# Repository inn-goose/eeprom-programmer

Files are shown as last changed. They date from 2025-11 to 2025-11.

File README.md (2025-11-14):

# EEPROM Programmer

> [!IMPORTANT]
> This project concerns **external** EEPROM chips, not the built-in Arduino EEPROM memory.

## TLDR

🚧 WIP 🚧

## Wiring Diagram

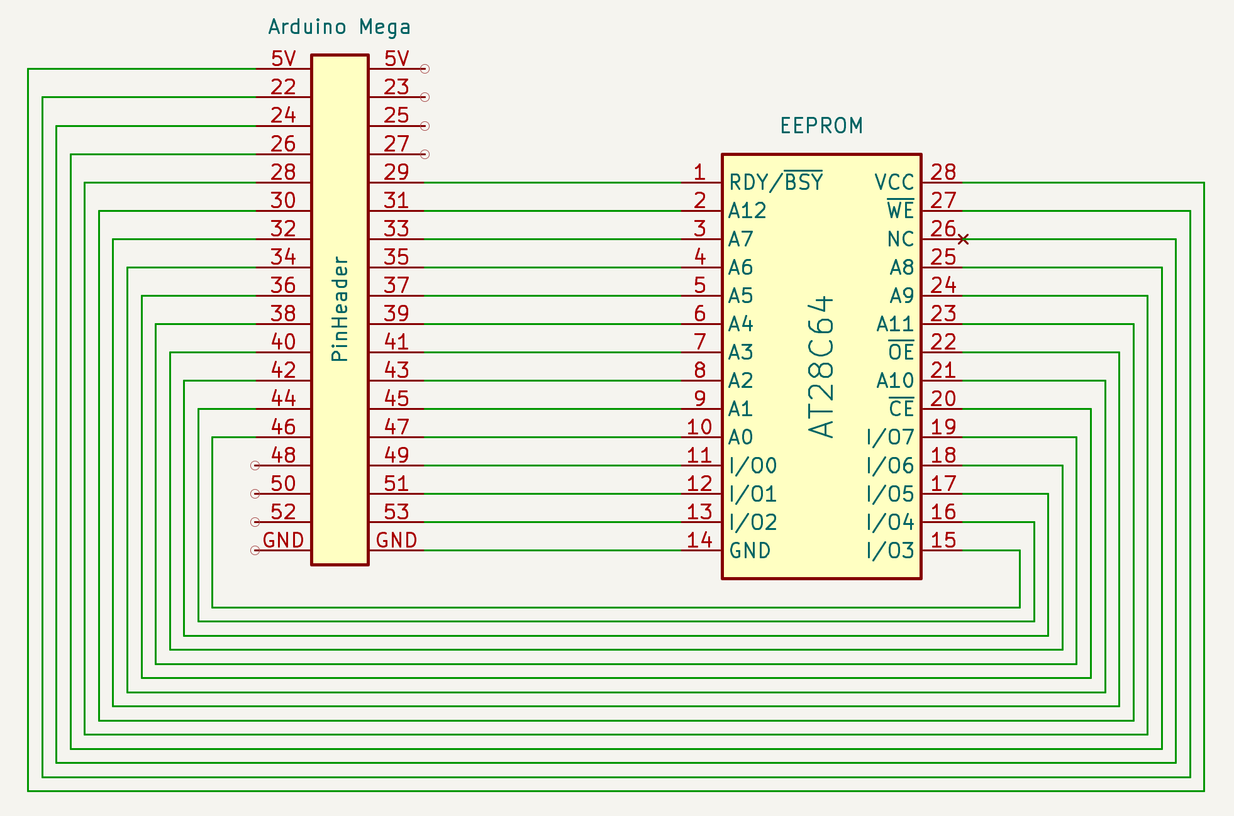
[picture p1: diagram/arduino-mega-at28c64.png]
Wiring Diagram: Arduino Mega and AT28C64


## EEPROM Programmer on Arduino

set pins layout in `eeprom_wiring.h`

Programmer interface:
```cpp
// initialize chip pinout 
ErrorCode init_chip(const String& chip_type);

// set read mode
ErrorCode set_read_mode(const int page_size_bytes);

// read one page
ErrorCode read_page(const int page_no, uint8_t* bytes);

// set write mode
ErrorCode set_write_mode(const int page_size_bytes);

// write one page
ErrorCode write_page(const int page_no, const uint8_t* bytes);
```

### JSON-RPC API

Arduino IDE's *Serial Monitor* on `115200` baud

`init_chip(chip_type: str)`

```json
{"jsonrpc":"2.0", "id":0, "method": "init_chip", "params": ["AT28C64"]}
```

`set_read_mode(page_size_bytes: int)`

```json
{"jsonrpc":"2.0", "id":0, "method": "set_read_mode", "params": [4]}
```

`read_page(page_no: int)`

```json
{"jsonrpc":"2.0", "id":0, "method": "read_page", "params": [0]}
```

`set_write_mode(page_size_bytes: int)`

```json
{"jsonrpc":"2.0", "id":0, "method": "set_write_mode", "params": [4]}
```

`write_page(page_no: int, data: array[int])`

```json
{"jsonrpc":"2.0", "id":0, "method": "write_page","params": [0, [127, 127, 127, 127]]}
```

#### Write Operation Sequence

```json
{"jsonrpc":"2.0", "id":0, "method": "init_chip", "params": ["AT28C64"]}
{"jsonrpc":"2.0", "id":0, "method": "set_write_mode", "params": [4]}
{"jsonrpc":"2.0", "id":0, "method": "write_page","params": [0, [120, 130, 140, 150]]}
{"jsonrpc":"2.0", "id":0, "method": "write_page","params": [50, [20, 30, 40, 50]]}
{"jsonrpc":"2.0", "id":0, "method": "get_write_perf","params": []}
```

#### Read Operation Sequence

```json
{"jsonrpc":"2.0", "id":0, "method": "init_chip", "params": ["AT28C64"]}
{"jsonrpc":"2.0", "id":0, "method": "set_read_mode", "params": [4]}
{"jsonrpc":"2.0", "id":0, "method": "read_page", "params": [0]}
{"jsonrpc":"2.0", "id":0, "method": "read_page", "params": [50]}
```

## EEPROM Programmer python CLI

> [!CAUTION]
> During read operations with the EEPROM Programmer, the chip's `!WE` pin **MUST** be connected to `VCC` using a jumper wire to disable the write mode. Otherwise, invoking the CLI may corrupt data on the chip due to Arduino's internal behavior. [Details](https://goose.sh/blog/eeprom-programmer-5-data-corruption/)

Uses the [Serial JSON RPC](https://github.com/inn-goose/serial-json-rpc-arduino) interface.

### init CLI

```bash
pip3 install virtualenv

PATH=${PATH}:~/Library/Python/3.9/bin/ ./env/init.sh

source venv/bin/activate

deactivate
```

### Usage

```bash
source venv/bin/activate

python3 -m serial.tools.list_ports
...
/dev/cu.usbmodem2101
```

#### prepare data

```bash
mkdir ./tmp

# get a "real" EEPROM dump
curl -LJ --output tmp/zenith_zt1_eeprom.bin "https://github.com/misterblack1/zenith_zt1/raw/refs/heads/main/444-187%20U114%20ROM%202732.bin"
```

#### read

```bash
source venv/bin/activate
export PYTHONPATH=./eeprom_programmer_cli/:$PYTHONPATH

# read data to file
./eeprom_programmer_cli/cli.py /dev/cu.usbmodem2101 -p AT28C64 --read tmp/dump_eeprom.bin

# convert to HEX
xxd tmp/dump_eeprom.bin > tmp/dump_eeprom.hex
```

#### erase

```bash
source venv/bin/activate
export PYTHONPATH=./eeprom_programmer_cli/:$PYTHONPATH

# erase with FF pattern
./eeprom_programmer_cli/cli.py /dev/cu.usbmodem2101 -p AT28C64 --erase --erase-pattern FF
```

#### write

```bash
source venv/bin/activate
export PYTHONPATH=./eeprom_programmer_cli/:$PYTHONPATH

# write data from file
./eeprom_programmer_cli/cli.py /dev/cu.usbmodem2101 -p AT28C64 --write test_bin/4_echo_orbit.bin

# skip erase
./eeprom_programmer_cli/cli.py /dev/cu.usbmodem2101 -p AT28C64 --write test_bin/4_echo_orbit.bin --skip-erase

# custom erase pattern
./eeprom_programmer_cli/cli.py /dev/cu.usbmodem2101 -p AT28C64 --write test_bin/4_echo_orbit.bin --erase-pattern CC
```

#### verify

```bash
source venv/bin/activate
export PYTHONPATH=./eeprom_programmer_cli/:$PYTHONPATH

# read data and verify it against the file
./eeprom_programmer_cli/cli.py /dev/cu.usbmodem2101 -p AT28C64 --verify test_bin/4_echo_orbit_AT28C64_ff.bin
```

## XGecu Programmer as a Reference

Use the [`minipro`](https://formulae.brew.sh/formula/minipro) utility to perform read and write operations with the XGecu programmer

```bash
brew install minipro

# write the "real" dump to the chip
minipro --device AT28C64 -s -u --write test_bin/4_echo_orbit.bin
minipro --device AT28C64 -s -u --write test_bin/64_the_red_migration.bin
minipro --device AT28C256 -s -u --write test_bin/256_the_geometry_of_flight.bin

# read the data
minipro --device AT28C64 -u --read tmp/dump_xgecu.bin
minipro --device AT28C256 -u --read tmp/dump_xgecu.bin

# convert to HEX
xxd tmp/dump_xgecu.bin > tmp/dump_xgecu.hex

# compare
vimdiff tmp/dump_eeprom.hex tmp/dump_xgecu.hex
```

## Tests

### prepare

```bash
source venv/bin/activate
export PYTHONPATH=./eeprom_programmer_cli/:$PYTHONPATH
```

### erase

```bash
# >> remove jumper wire
./eeprom_programmer_cli/cli.py /dev/cu.usbmodem2101 -p AT28C64 --erase --erase-pattern BB --collect-write-performance

# >> set jumper wire
./eeprom_programmer_cli/cli.py /dev/cu.usbmodem2101 -p AT28C64 --read tmp/dump_eeprom.bin

xxd tmp/dump_eeprom.bin | less
```

### write and read

```bash
# >> remove jumper wire
./eeprom_programmer_cli/cli.py /dev/cu.usbmodem2101 -p AT28C64 --write test_bin/4_echo_orbit.bin --erase-pattern BB --collect-write-performance

# >> set jumper wire
./eeprom_programmer_cli/cli.py /dev/cu.usbmodem2101 -p AT28C64 --read tmp/dump_eeprom.bin

xxd tmp/dump_eeprom.bin > tmp/dump_eeprom.hex
vimdiff tmp/dump_eeprom.hex tmp/4_echo_orbit.hex
```

### verify

```bash
# >> remove jumper wire
./eeprom_programmer_cli/cli.py /dev/cu.usbmodem2101 -p AT28C64 --write test_bin/4_echo_orbit.bin --collect-write-performance

# >> set jumper wire
./eeprom_programmer_cli/cli.py /dev/cu.usbmodem2101 -p AT28C64 --verify test_bin/4_echo_orbit_AT28C64_ff.bin
```

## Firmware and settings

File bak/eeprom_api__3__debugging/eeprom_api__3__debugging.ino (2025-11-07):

#include "eeprom_wiring.h"
#include "eeprom_28c64_api.h"

using namespace EepromApiLibrary;


// helper functions

enum LedColor { NO_LED_,
                LED_RED_,
                LED_GREEN_,
                LED_BLUE_ };

void setBuiltinLed(LedColor led_color) {
#ifdef LEDR
  // reverse logic. HIGH == off, LOW == on
  switch (led_color) {
    case LedColor::LED_RED_:
      digitalWrite(LEDR, LOW);
      digitalWrite(LEDG, HIGH);
      digitalWrite(LEDB, HIGH);
      break;
    case LedColor::LED_GREEN_:
      digitalWrite(LEDR, HIGH);
      digitalWrite(LEDG, LOW);
      digitalWrite(LEDB, HIGH);
      break;
    case LedColor::LED_BLUE_:
      digitalWrite(LEDR, HIGH);
      digitalWrite(LEDG, HIGH);
      digitalWrite(LEDB, LOW);
      break;
    case LedColor::NO_LED_:
    default:
      digitalWrite(LEDR, HIGH);
      digitalWrite(LEDG, HIGH);
      digitalWrite(LEDB, HIGH);
      break;
  }
#else
  switch (led_color) {
    case LedColor::LED_RED_:
    case LedColor::LED_GREEN_:
    case LedColor::LED_BLUE_:
      digitalWrite(LED_BUILTIN, HIGH);
      break;
    default:
      digitalWrite(LED_BUILTIN, LOW);
      break;
  }
#endif
}


// EEPROM 28C64

Eeprom28C64Api eeprom28C64Api(
  // address
  EEPROM_ADDRESS_PINS,
  // data
  EEPROM_DATA_PINS,
  // management
  EEPROM_CHIP_ENABLE_PIN,
  EEPROM_OUTPUT_ENABLE_PIN,
  EEPROM_WRITE_ENABLE_PIN,
  // status
  EEPROM_READY_BUSY_OUTPUT_PIN);


void setup() {
  Serial.begin(115200);
  // Serial.begin(9600);
  // LED
#ifndef LEDR
  pinMode(LED_BUILTIN, OUTPUT);
  digitalWrite(LED_BUILTIN, LOW);
#endif
  // eeprom
  eeprom28C64Api.init();
  // NC to 0
  pinMode(24, OUTPUT);
  digitalWrite(24, LOW);
}


const int ADDRESS_SPACE_SIZE = 8192;
const int USABLE_ADDRESS_OFFSET = 0;
const int USABLE_ADDRESS_SPACE_SIZE = 8192;
const int BUFFER_SIZE = 16;
// uint8_t writeValues[ADDRESS_SPACE_SIZE];
// int busyStateUsec[ADDRESS_SPACE_SIZE];
// uint8_t readValues[ADDRESS_SPACE_SIZE];
uint8_t readBuffer[BUFFER_SIZE];
// bool damagedCells[ADDRESS_SPACE_SIZE];
// int damagedCellsTotal = 0;

bool op_init = true;
// int op_write = -1;
int op_read = -1;
bool op_verify = false;

// int write_total_micros = 0;
int read_total_micros = 0;

void loop() {
  if (op_init) {
    delay(1000);
    op_init = false;
    op_read = 0;
  }

  // if (op_write >= 0) {
  //   // init
  //   if (op_write == 0) {
  //     setBuiltinLed(LedColor::LED_RED_);
  //     eeprom28C64Api.writeInit();
  //   }

  //   uint16_t address = (uint16_t)(USABLE_ADDRESS_OFFSET + op_write);
  //   uint8_t data = (uint8_t)random(1, 255);
  //   // uint8_t data = (uint8_t)op_write;

  //   writeValues[USABLE_ADDRESS_OFFSET + op_write] = data;

  //   int write_start = micros();
  //   eeprom28C64Api.writeData(address, data);
  //   write_total_micros += micros() - write_start;

  //   busyStateUsec[USABLE_ADDRESS_OFFSET + op_write] = eeprom28C64Api.busyStateUsec();

  //   Serial.println("W [" + String(address) + "] addr: " + getAddressStrBin(address) + " | data: " + getDataStrHex(data));

  //   op_write += 1;
  //   // deinit
  //   if (op_write > USABLE_ADDRESS_SPACE_SIZE) {
  //     setBuiltinLed(LedColor::NO_LED_);
  //     op_write = -1;
  //     op_read = 0;
  //     Serial.flush();
  //     delay(500);
  //     return;
  //   }
  // }

  if (op_read >= 0) {
    // init
    if (op_read == 0) {
      setBuiltinLed(LedColor::LED_BLUE_);
      eeprom28C64Api.readInit();
    }

    uint16_t address = (uint16_t)(USABLE_ADDRESS_OFFSET + op_read);

    int read_start = micros();
    uint8_t data = eeprom28C64Api.readData(address);
    read_total_micros += micros() - read_start;
    // readValues[address] = data;

    // Serial.println("R [" + String(address) + "] addr: " + Eeprom28C64Api::addressHex(address) + " | data: " + Eeprom28C64Api::dataHex(data));

    int bufferIndex = op_read % BUFFER_SIZE;
    if (bufferIndex == 0 && op_read != 0) {
      String dataHex;
      String dataAscii;
      for (int i = 0; i < BUFFER_SIZE; i++) {
        dataHex += Eeprom28C64Api::dataHex(readBuffer[i]);
        if (i % 2 == 1) {
          dataHex += " ";
        }
        if ((readBuffer[i] >= 33 && readBuffer[i] <= 126) || readBuffer[i] == 20 /*space*/) {
          dataAscii += String((char)readBuffer[i]);
        } else {
          dataAscii += ".";
        }
      }
      uint16_t startAddress = address - BUFFER_SIZE;
      // Serial.println(Eeprom28C64Api::addressHex(startAddress) + " [" + Eeprom28C64Api::addressBin(startAddress) + "]" + ": " + dataHex + " " + dataAscii);
      Serial.println(Eeprom28C64Api::addressHex(startAddress) + ": " + dataHex + " " + dataAscii);
    }

    readBuffer[bufferIndex] = data;

    op_read += 1;
    // deinit
    if (op_read > USABLE_ADDRESS_SPACE_SIZE) {
      setBuiltinLed(LedColor::NO_LED_);
      op_read = -1;
      op_verify = true;
      Serial.flush();
      delay(500);
      return;
    }
  }

  if (op_verify) {
    op_verify = false;

    // check damaged cells
    // for (int i = USABLE_ADDRESS_OFFSET; i < USABLE_ADDRESS_OFFSET + USABLE_ADDRESS_SPACE_SIZE; i++) {
    //   if (writeValues[i] != readValues[i]) {
    //     damagedCells[i] = true;
    //     damagedCellsTotal += 1;
    //     Serial.println(getAddressStrBin(i) + " | W: " + getDataStrHex(writeValues[i]) + " | R: " + getDataStrHex(readValues[i]));
    //   }
    // }

    // int busyStateUsecTotal = 0;
    // int busyStateUsecMax = 0;
    // for (int i = USABLE_ADDRESS_OFFSET; i < USABLE_ADDRESS_OFFSET + USABLE_ADDRESS_SPACE_SIZE; i++) {
    //   busyStateUsecTotal += busyStateUsec[i];
    //   busyStateUsecMax = max(busyStateUsecMax, busyStateUsec[i]);
    // }
    // Serial.println("B | T: " + String(busyStateUsecTotal) + " us | AVG: " + String(busyStateUsecTotal / USABLE_ADDRESS_SPACE_SIZE) + " us | MAX: " + String(busyStateUsecMax) + " us");

    // Serial.println("W | T: " + String(write_total_micros) + " us | AVG: " + String(write_total_micros / USABLE_ADDRESS_SPACE_SIZE) + " us");
    Serial.println("R | T: " + String(read_total_micros) + " us | AVG: " + String(read_total_micros / USABLE_ADDRESS_SPACE_SIZE) + " us");
    // if (damagedCellsTotal) {
    //   Serial.println("VERIFY: damagedCellsTotal: " + String(damagedCellsTotal));
    // } else {
    //   Serial.println("VERIFY: OK");
    // }

    Serial.flush();
    delay(500);
    return;
  }
}

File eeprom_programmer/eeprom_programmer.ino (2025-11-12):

#include "eeprom_programmer_wiring.h"
#include "eeprom_programmer_lib.h"
#include "serial_json_rpc_lib.h"

using namespace EepromProgrammerLibrary;
using namespace EepromProgrammerWiring;
using namespace SerialJsonRpcLibrary;


// EEPROM Programmer

static EepromProgrammer eeprom_programmer(WiringType::DIP28);


// Serial JSON RPC Processor

static SerialJsonRpcBoard rpc_board(rpc_processor);

void rpc_processor(int request_id, const String &method, const String params[], int params_size) {
  if (method == "init_chip") {
    if (params_size != 1) {
      rpc_board.send_error(request_id, -32602, "Invalid params", "expected: (chip_type)");
      return;
    }
    String chip_type = params[0];

    ErrorCode code = eeprom_programmer.init_chip(chip_type);
    if (code != ErrorCode::SUCCESS) {
      const size_t error_data_buf_size = 50;
      char error_data_buf[error_data_buf_size];
      snprintf(error_data_buf, error_data_buf_size, "Failed to init %s chip with error: %d", chip_type.c_str(), code);
      rpc_board.send_error(request_id, -32010, "Service error", error_data_buf);
      return;
    }

    int32_t chip_settings[] = {
      eeprom_programmer.get_memory_size_bytes(),
      eeprom_programmer.get_max_page_size(),
    };
    rpc_board.send_result_ints(request_id, chip_settings, sizeof(chip_settings) / sizeof(chip_settings[0]));

  } else if (method == "set_read_mode") {
    if (params_size != 1) {
      rpc_board.send_error(request_id, -32602, "Invalid params", "expected: (read_page_size_bytes)");
      return;
    }
    const int read_page_size_bytes = atoi(params[0].c_str());

    ErrorCode code = eeprom_programmer.set_read_mode(read_page_size_bytes);
    if (code != ErrorCode::SUCCESS) {
      const size_t error_data_buf_size = 70;
      char error_data_buf[error_data_buf_size];
      snprintf(error_data_buf, error_data_buf_size, "Failed to set READ mode for page size %d with error: %d", read_page_size_bytes, code);
      rpc_board.send_error(request_id, -32020, "Service error", error_data_buf);
      return;
    }

    const size_t result_buf_size = 50;
    char result_buf[result_buf_size];
    snprintf(result_buf, result_buf_size, "READ mode is ON for %d bytes pages", read_page_size_bytes);
    rpc_board.send_result_string(request_id, result_buf);

  } else if (method == "read_page") {
    if (params_size != 1) {
      rpc_board.send_error(request_id, -32602, "Invalid params", "expected: (page_no)");
      return;
    }
    const int page_no = atoi(params[0].c_str());

    const size_t page_size = eeprom_programmer.get_page_size_bytes();
    uint8_t buffer[page_size];

    ErrorCode code = eeprom_programmer.read_page(page_no, buffer);
    if (code != ErrorCode::SUCCESS) {
      const size_t error_data_buf_size = 70;
      char error_data_buf[error_data_buf_size];
      snprintf(error_data_buf, error_data_buf_size, "Failed to READ page %d with error: %d", page_no, code);
      rpc_board.send_error(request_id, -32021, "Service error", error_data_buf);
      return;
    }

    rpc_board.send_result_bytes(request_id, buffer, page_size);

  } else if (method == "set_write_mode") {
    if (params_size != 1) {
      rpc_board.send_error(request_id, -32602, "Invalid params", "expected: (write_page_size_bytes)");
      return;
    }
    const int write_page_size_bytes = atoi(params[0].c_str());

    ErrorCode code = eeprom_programmer.set_write_mode(write_page_size_bytes);
    if (code != ErrorCode::SUCCESS) {
      const size_t error_data_buf_size = 70;
      char error_data_buf[error_data_buf_size];
      snprintf(error_data_buf, error_data_buf_size, "Failed to set WRITE mode for page size %d with error: %d", write_page_size_bytes, code);
      rpc_board.send_error(request_id, -32030, "Service error", error_data_buf);
      return;
    }

    const size_t result_buf_size = 50;
    char result_buf[result_buf_size];
    snprintf(result_buf, result_buf_size, "WRITE mode is ON for %d bytes pages", write_page_size_bytes);
    rpc_board.send_result_string(request_id, result_buf);

  } else if (method == "write_page") {
    if (params_size != 2) {
      rpc_board.send_error(request_id, -32602, "Invalid params", "expected: (page_no, bytes_to_write)");
      return;
    }
    const int page_no = atoi(params[0].c_str());

    const size_t page_size = eeprom_programmer.get_page_size_bytes();
    uint8_t buffer[page_size];
    const size_t json_array_size = SerialJsonRpcBoard::json_array_to_byte_array(params[1], buffer, page_size);

    ErrorCode code = eeprom_programmer.write_page(page_no, buffer, json_array_size);
    if (code != ErrorCode::SUCCESS) {
      const size_t error_data_buf_size = 70;
      char error_data_buf[error_data_buf_size];
      snprintf(error_data_buf, error_data_buf_size, "Failed to WRITE page %d with error: %d", page_no, code);
      rpc_board.send_error(request_id, -32031, "Service error", error_data_buf);
      return;
    }

    const size_t result_buf_size = 50;
    char result_buf[result_buf_size];
    snprintf(result_buf, result_buf_size, "WRITE success. %d bytes written", json_array_size);
    rpc_board.send_result_string(request_id, result_buf);

  } else if (method == "get_write_perf") {
    const size_t page_size = eeprom_programmer.get_page_size_bytes();
    unsigned long wait_time_for_page[page_size];
    eeprom_programmer.get_write_op_wait_time_usec_for_page(wait_time_for_page, page_size);

    rpc_board.send_result_ints(request_id, wait_time_for_page, page_size);

  } else {
    rpc_board.send_error(request_id, -32601, "Method not found", method.c_str());
  }
}


// Arduino

void setup() {
  // rpc board
  rpc_board.init();
  // eeprom programmer
  eeprom_programmer.init_programmer();
}

void loop() {
  rpc_board.loop();
}

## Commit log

2025-10-25 add erase mode to board and CLI
2025-10-25 fix bit-ordering for write operations on the board level
    [eeprom_api.h]
2025-10-26 new board RPC API
2025-10-26 add error processing to the new board API
    [eeprom_api.h]
2025-11-05 add wiring diagram
    [eeprom_programmer.kicad_sch]
2025-11-05 update wiring diagram
    [eeprom_programmer.kicad_sch]
2025-11-05 fix address conversion issues
    [eeprom_programmer_lib.h]
2025-11-08 start working on DIP wiring
2025-11-11 add WiringType
2025-11-11 get address pins from wiring controller
2025-11-11 get data pins from wiring controller
2025-11-11 rollback wiring changes
2025-11-11 prepare wiring
2025-11-11 add WiringController
2025-11-11 use address from wiring
2025-11-11 use wiring for data with a hack
2025-11-11 use wiring for management pins
2025-11-11 cleanup wiring
2025-11-12 fix write op wait logic
    [eeprom_programmer_lib.h]
2025-11-12 fix address issues: use uint32_t instead of int for all addresses
    [eeprom_programmer_lib.h]
